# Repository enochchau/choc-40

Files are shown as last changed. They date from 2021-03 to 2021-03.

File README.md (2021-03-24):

# 40% Kailh choc v1 keyboard

Inspired by the [Contra](https://github.com/ai03-2725/Contra).

Estimated cost:
* PCB, Plate, and Base plate: $30
* Pro-Micro: $5
* keycaps: $20
* standoffs and screws: $5
* 48 Switches: $30
* diodes: $5
* reset switch: $0.30

Total: $95.30
Shipping: $20

Switches are spaced 18.55mm x 19mm apart (width x length). 
This should be large enough for any style of choc-v1 switch keycaps.
Plate spacing is 13.8mmx13.8mm.

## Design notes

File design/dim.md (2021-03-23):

# Dimensions
https://plate.keeb.io/
## Keycap width x length
* [17.5mm x 17.95mm](https://splitkb.com/products/kailh-choc-transparent-keycaps)
* [17.5mm * 16.5mm](https://splitkb.com/products/blank-mbk-choc-low-profile-keycaps?_pos=1&_sid=49b3f7271&_ss=r)

Cherry keycaps are 18x18mm with a 19.05x19.05mm spacing.
cherry keycap dimensions

* using largest dim: 18.55mm x 19mm

## CAD

* fillet: 2.5mm
* spacing: 18.55mm x 19mm

## [PJ320A TRRS](https://images-na.ssl-images-amazon.com/images/I/41tsh%2BKuNWL._AC_.jpg)

* Height: 5mm

## Pro Micro

| Part | Hieght |
| ---  | --- |
| [Usb Micro connector](https://qph.fs.quoracdn.net/main-qimg-a146c969b048f1b117a71e0d7b1651de.webp) | 2.35mm |
| PCB  | 1.8mm |
* Total: 4.15

## Header Pins

* 2.5mm

## [SIP socket](https://www.jiatel.com/wp-content/uploads/2018/09/4.82-SIP-SOCKET.jpg)

* 4.5mm sticking out of the PCB

## Total
Side | Height
--- | ---
With header pins, component side up     | 6.65mm
With header pins, component side down   | 4.3mm
With sip socket, component side up      | 8.7mm
With sip socket component side down     | 6.3mm

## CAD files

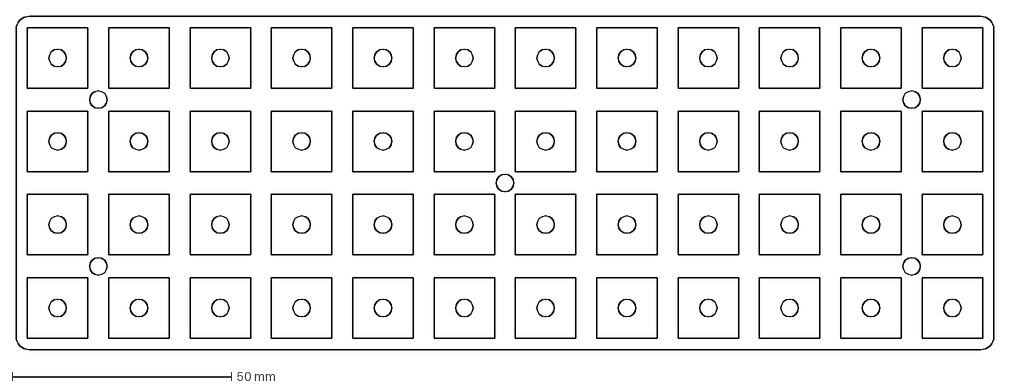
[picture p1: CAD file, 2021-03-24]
design/1855x19.dxf
223.0 x 76.0 mm

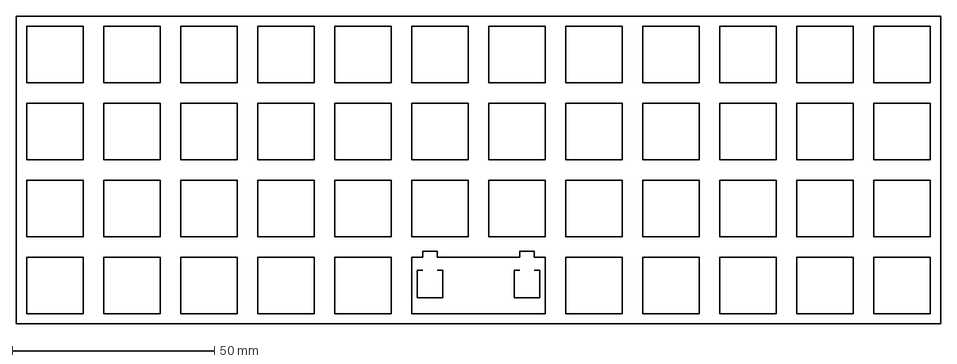
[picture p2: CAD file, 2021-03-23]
design/1905x1905.dxf
228.5 x 76.1 mm

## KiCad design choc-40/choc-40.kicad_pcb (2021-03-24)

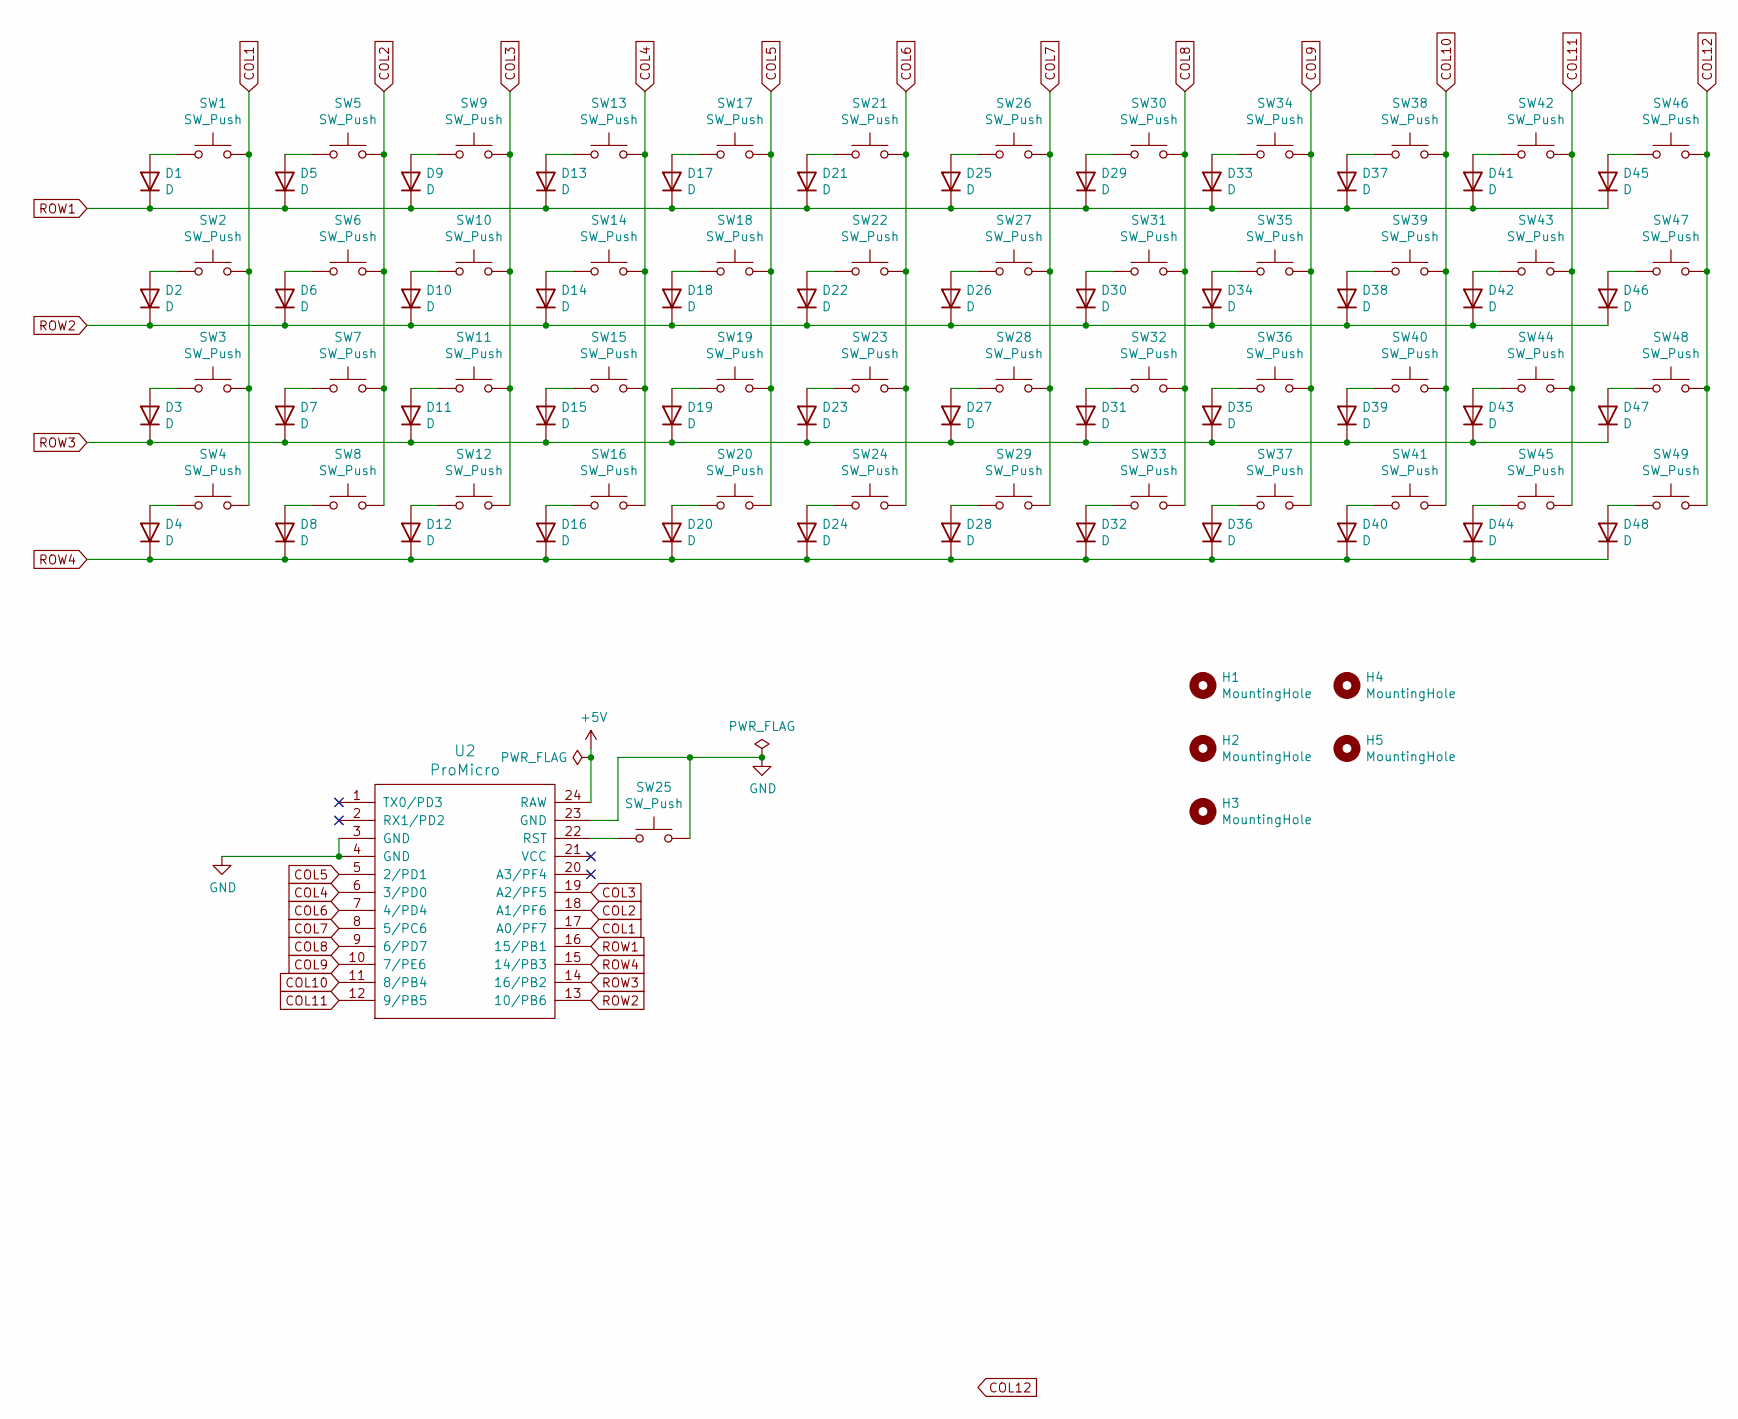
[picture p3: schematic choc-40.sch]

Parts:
D1, D2, D3, D4, D5, D6, D7, D8, D9, D10, D11, D12, D13, D14, D15, D16, D17, D18, D19, D20, D21, D22, D23, D24, D25, D26, D27, D28, D29, D30, D31, D32, D33, D34, D35, D36, D37, D38, D39, D40, D41, D42, D43, D44, D45, D46, D47, D48: D; D_SOD123_axial
H1, H2, H3, H4, H5: MountingHole; MountingHole_2.2mm_M2_Pad_Via
SW1, SW2, SW3, SW4, SW5, SW6, SW7, SW8, SW9, SW10, SW11, SW12, SW13, SW14, SW15, SW16, SW17, SW18, SW19, SW20, SW21, SW22, SW23, SW24, SW26, SW27, SW28, SW29, SW30, SW31, SW32, SW33, SW34, SW35, SW36, SW37, SW38, SW39, SW40, SW41, SW42, SW43, SW44, SW45, SW46, SW47, SW48, SW49: SW_Push; Kailh-PG1350-1u-NoLED
SW25: SW_Push; SW_SPST_PTS810
U2: ProMicro; ArduinoProMicro-TopSide

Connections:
COL1: SW1.2, SW2.2, SW3.2, SW4.2, U2.17 (A0/PF7)
COL2: SW5.2, SW6.2, SW7.2, SW8.2, U2.18 (A1/PF6)
COL3: SW9.2, SW10.2, SW11.2, SW12.2, U2.19 (A2/PF5)
COL4: SW13.2, SW14.2, SW15.2, SW16.2, U2.6 (3/PD0)
COL5: SW17.2, SW18.2, SW19.2, SW20.2, U2.5 (2/PD1)
COL6: SW21.2, SW22.2, SW23.2, SW24.2, U2.7 (4/PD4)
COL7: SW26.2, SW27.2, SW28.2, SW29.2, U2.8 (5/PC6)
COL8: SW30.2, SW31.2, SW32.2, SW33.2, U2.9 (6/PD7)
COL9: SW34.2, SW35.2, SW36.2, SW37.2, U2.10 (7/PE6)
COL10: SW38.2, SW39.2, SW40.2, SW41.2, U2.11 (8/PB4)
COL11: SW42.2, SW43.2, SW44.2, SW45.2, U2.12 (9/PB5)
COL12: SW46.2, SW47.2, SW48.2, SW49.2
GND: SW25.2, U2.3 (GND), U2.4 (GND), U2.23 (GND)
unnamed: D1.2 (A), SW1.1
unnamed: D2.2 (A), SW2.1
unnamed: D3.2 (A), SW3.1
unnamed: D4.2 (A), SW4.1
unnamed: D5.2 (A), SW5.1
unnamed: D6.2 (A), SW6.1
unnamed: D7.2 (A), SW7.1
unnamed: D8.2 (A), SW8.1
unnamed: D9.2 (A), SW9.1
unnamed: D10.2 (A), SW10.1
unnamed: D11.2 (A), SW11.1
unnamed: D12.2 (A), SW12.1
unnamed: D13.2 (A), SW13.1
unnamed: D14.2 (A), SW14.1
unnamed: D15.2 (A), SW15.1
unnamed: D16.2 (A), SW16.1
unnamed: D17.2 (A), SW17.1
unnamed: D18.2 (A), SW18.1
unnamed: D19.2 (A), SW19.1
unnamed: D20.2 (A), SW20.1
unnamed: D21.2 (A), SW21.1
unnamed: D22.2 (A), SW22.1
unnamed: D23.2 (A), SW23.1
unnamed: D24.2 (A), SW24.1
unnamed: D25.2 (A), SW26.1
unnamed: D26.2 (A), SW27.1
unnamed: D27.2 (A), SW28.1
unnamed: D28.2 (A), SW29.1
unnamed: D29.2 (A), SW30.1
unnamed: D30.2 (A), SW31.1
unnamed: D31.2 (A), SW32.1
unnamed: D32.2 (A), SW33.1
unnamed: D33.2 (A), SW34.1
unnamed: D34.2 (A), SW35.1
unnamed: D35.2 (A), SW36.1
unnamed: D36.2 (A), SW37.1
unnamed: D37.2 (A), SW38.1
unnamed: D38.2 (A), SW39.1
unnamed: D39.2 (A), SW40.1
unnamed: D40.2 (A), SW41.1
unnamed: D41.2 (A), SW42.1
unnamed: D42.2 (A), SW43.1
unnamed: D43.2 (A), SW44.1
unnamed: D44.2 (A), SW45.1
unnamed: D45.2 (A), SW46.1
unnamed: D46.2 (A), SW47.1
unnamed: D47.2 (A), SW48.1
unnamed: D48.2 (A), SW49.1
unnamed: SW25.1, U2.22 (RST)
ROW1: D1.1 (K), D5.1 (K), D9.1 (K), D13.1 (K), D17.1 (K), D21.1 (K), D25.1 (K), D29.1 (K), D33.1 (K), D37.1 (K), D41.1 (K), D45.1 (K), U2.16 (15/PB1)
ROW2: D2.1 (K), D6.1 (K), D10.1 (K), D14.1 (K), D18.1 (K), D22.1 (K), D26.1 (K), D30.1 (K), D34.1 (K), D38.1 (K), D42.1 (K), D46.1 (K), U2.13 (10/PB6)
ROW3: D3.1 (K), D7.1 (K), D11.1 (K), D15.1 (K), D19.1 (K), D23.1 (K), D27.1 (K), D31.1 (K), D35.1 (K), D39.1 (K), D43.1 (K), D47.1 (K), U2.14 (16/PB2)
ROW4: D4.1 (K), D8.1 (K), D12.1 (K), D16.1 (K), D20.1 (K), D24.1 (K), D28.1 (K), D32.1 (K), D36.1 (K), D40.1 (K), D44.1 (K), D48.1 (K), U2.15 (14/PB3)

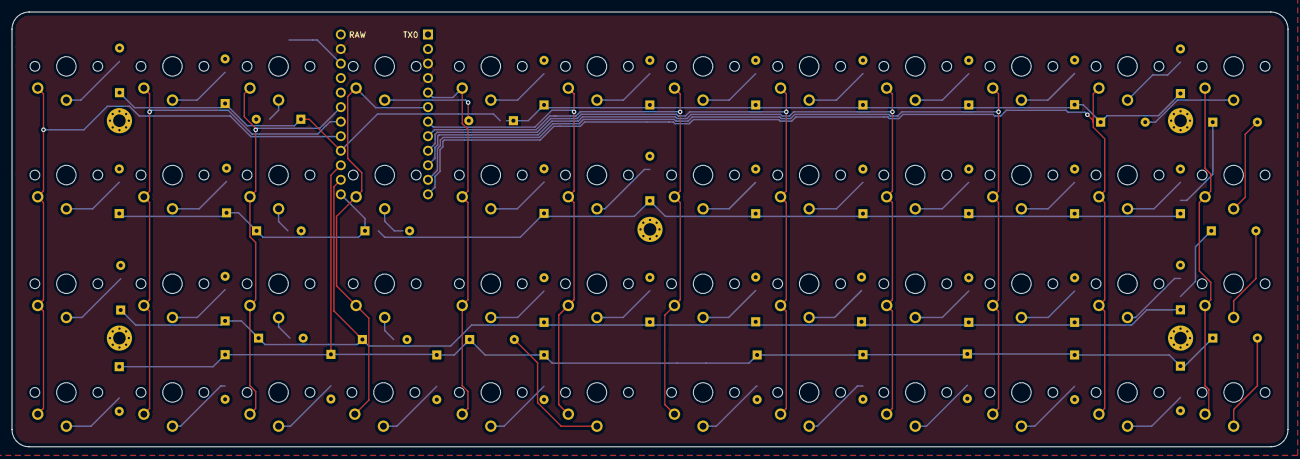
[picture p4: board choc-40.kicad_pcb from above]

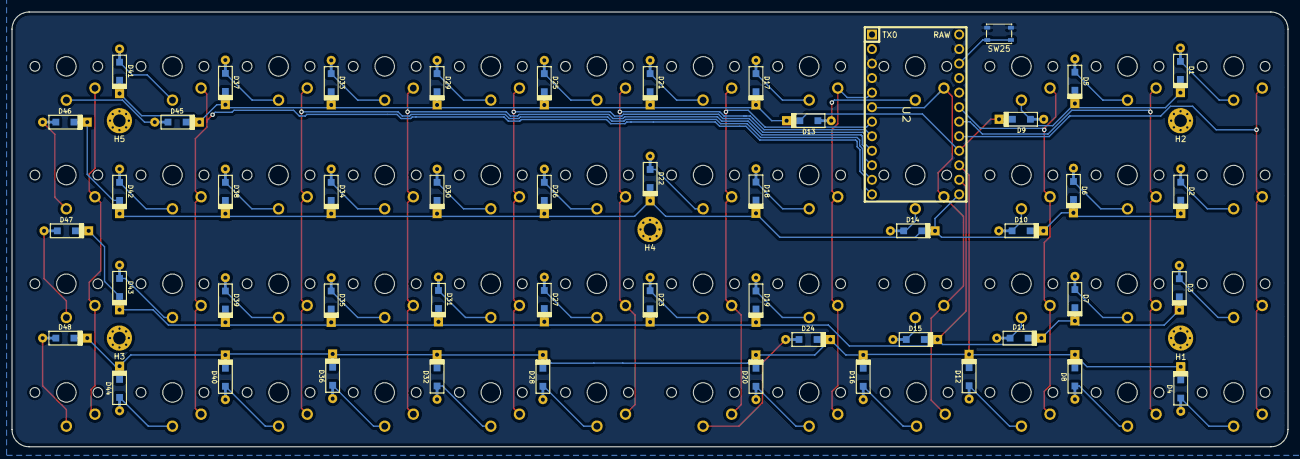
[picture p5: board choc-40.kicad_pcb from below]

Board: 2 copper layers, 223.1 x 76.0 mm, 103 parts (55 on the bottom side), 66 nets.

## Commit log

2021-03-20 cleaning up lib
    [choc-40.kicad_pcb, choc-40.sch]
2021-03-20 remove temp cad files
2021-03-20 adding gerbers
    [choc-40-B_Cu.gbr, choc-40-B_Mask.gbr, choc-40-B_SilkS.gbr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]
2021-03-23 adding 2u middle key option
    [choc-40.kicad_pcb, choc-40.sch]
2021-03-23 adding base and plate
    [1855x19.dxf, 1905x1905.dxf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]
2021-03-23 forgot to connect a trace
    [choc-40.kicad_pcb]
2021-03-24 removing 2u optional layout
    [base.kicad_pcb]
2021-03-24 updating plate to 13.8x13.8mm
    [1855x19.dxf, choc-40.kicad_pcb, choc-40.sch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]
